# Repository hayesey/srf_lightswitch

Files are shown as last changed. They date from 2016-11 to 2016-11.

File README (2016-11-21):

srf_lightswitch
-----
Originally written sometime in 2015
2016-11-17 put on github
2016-11-21 added filter info
-----

This is my home-made "IoT" light switch.  The idea is that you can retrofit this into a lamp or ceiling light to turn the light on and off remotely.  In addition you can connect up the existing bistable switch (i.e. the light switch) to also operate the light in order to maintain the operation people expect of a light & light switch.

It's based on a Texas Instruments CC1110 System-on-Chip.  The module I use is actually an SRF module from the sadly now defunct Ciseco/Wireless Things company.  This and all other components are mounted to a PCB of my own design.

It uses a PCB mounted mains voltage transformer, this actually powers the microcontroller and other parts of the circuit from the mains voltage going to the light itself.  No batteries are needed or any other means of power.

Files:

'SRF Light Switch' folder contains the design, layout and gerber files for the PCB.  The software I use is Cadsoft Eagle.  I used Seeedstudio Fusion PCB online service for the production of prototype boards.  They are very cheap but since the work is done in China, delivery takes weeks.

'Firmware' folder contains the C code for the CC1110 chip to make the light switch work.  I would definitely call it a prototype, it is probably full of bugs.  It has some basic LLAP commands to control the light switch from other devices such as Ciseco XRF modules.

To use this you'll need the Small Devices C Compiler (sdcc) and some way burning the compiled firmware on to the CC1110 device.  I use a proper TI CC-Debugger, they are under £40.  I believe a Raspberry Pi can also be used to bit-bang it.  See this:

http://paulswasteland.blogspot.co.uk/2015/01/building-your-own-firmware-for-ciseco.html

Use at your own risk anyone who finds this.  I only ever intended this to be for experimentation or fun.

Note - there was an error by me with the PCB layout that didn't come to light until after I had them produced.  This is that I hadn't included the low pass filter on the output of the 3.3v transformer.  Without this the radio performance is very poor.  I made a small veroboard circuit to add the filter, there is an eagle schematic and layout showing this and the parts are included in the BOM.  Values are from the datasheet for the Vigortronix transformer.

Paul Hayes.

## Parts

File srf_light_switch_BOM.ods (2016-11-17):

Part Code | Supplier | Description | Quantity | Price (ea)
2401029 | Farnell | VTX-214-003-103 3W, 3,3v transformer | 1 | £5.64
SRF | Ciseco/Wireless Things | SRF CC1110 surface mount module | 1 | £9.98
1103949 | Farnell | 2.54mm 10way header | 1 | £0.82
2293757 | Farnell | 2.54mm 6way header | 1 | £0.39
1891660 | Farnell | relay, spst-no, 250VAC, 30VDC, 10A | 1 | £0.50
3041440 | Farnell | terminal block, wire to board, 2way | 3 | £0.28
1651089 | Farnell | Diode 1N4001 | 1 | £0.06
1574379 | Farnell | Transistor, NPN, BC337 | 1 | £0.11
9339043 | Farnell | Resistor, 100ohm, +/-5%, 250mW | 1 | £0.04
2328785 | Farnell | 5uH SMD inductor | 1 | £0.41
9696946 | Farnell | 47uF SMD capacitor | 1 | £0.17
645680 | Farnell | enclosure, 25mm/73.5mm/51mm | 1 | £1.33
 |  |  | Total | £19.70

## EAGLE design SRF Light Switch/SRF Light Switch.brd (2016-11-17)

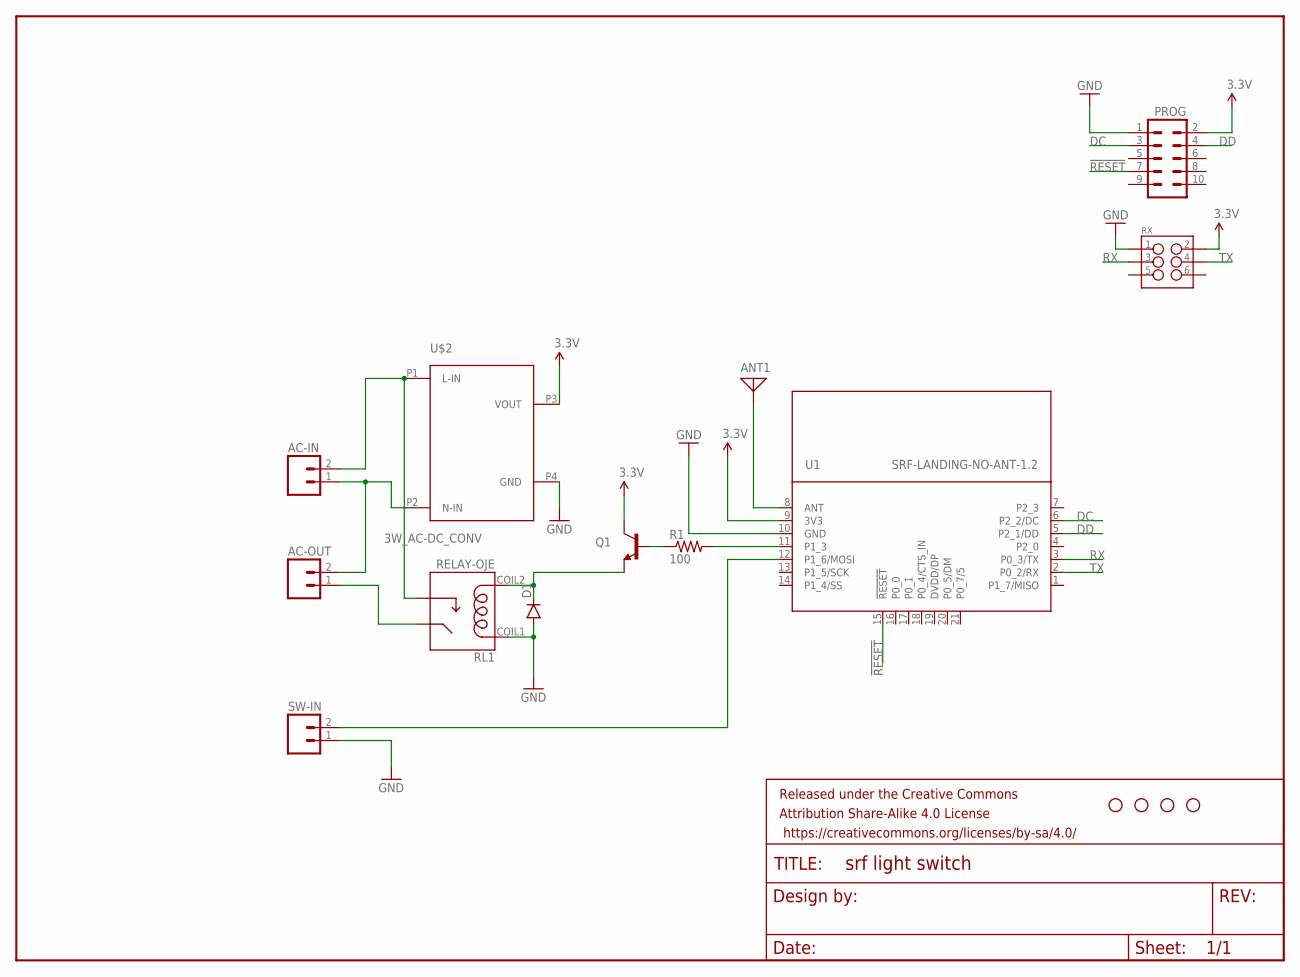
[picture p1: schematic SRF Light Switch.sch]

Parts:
AC-IN: M025MM; SCREWTERMINAL-5MM-2
AC-OUT: M025MM; SCREWTERMINAL-5MM-2
ANT1: ANTENNA; PAD-01
D1: DIODEPTH; DIODE-1N4001
FRAME1: FRAME-LETTER; CREATIVE_COMMONS
PROG: M05X2SHD; 2X5-SHROUDED
Q1: TRANSISTOR_NPNTO92; TO-92
R1: 100; AXIAL-0.4
RL1: RELAY-OJE
RX: M03X2SHROUD; 2X3-SHROUDED
STANDOFF1, STANDOFF2, STANDOFF3, STANDOFF4: STAND-OFF
SW-IN: M025MM; SCREWTERMINAL-5MM-2
U1: SRF-LANDING-NO-ANT-1.2
U$2: 3W_AC-DC_CONV

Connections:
3.3V: PROG.2, Q1.3 (C), RX.2, U1.9 (3V3), U$2.P3 (VOUT)
!RESET: PROG.7, U1.15 (!RESET)
ANT: ANT1.1, U1.8 (ANT)
DC: PROG.3, U1.6 (P2_2/DC)
DD: PROG.4, U1.5 (P2_1/DD)
GND: D1.A, PROG.1, RL1.COIL1, RX.1, SW-IN.1, U1.10 (GND), U$2.P4 (GND)
unnamed: D1.C, Q1.1 (E), RL1.COIL2
unnamed: AC-IN.2, RL1.NO, U$2.P1 (L-IN)
unnamed: SW-IN.2, U1.12 (P1_6/MOSI)
unnamed: Q1.2 (B), R1.P$1 (1)
unnamed: R1.P$2 (2), U1.11 (P1_3)
unnamed: AC-IN.1, AC-OUT.2, U$2.P2 (N-IN)
unnamed: AC-OUT.1, RL1.COM
RX: RX.3, U1.3 (P0_3/TX)
TX: RX.4, U1.2 (P0_2/RX)

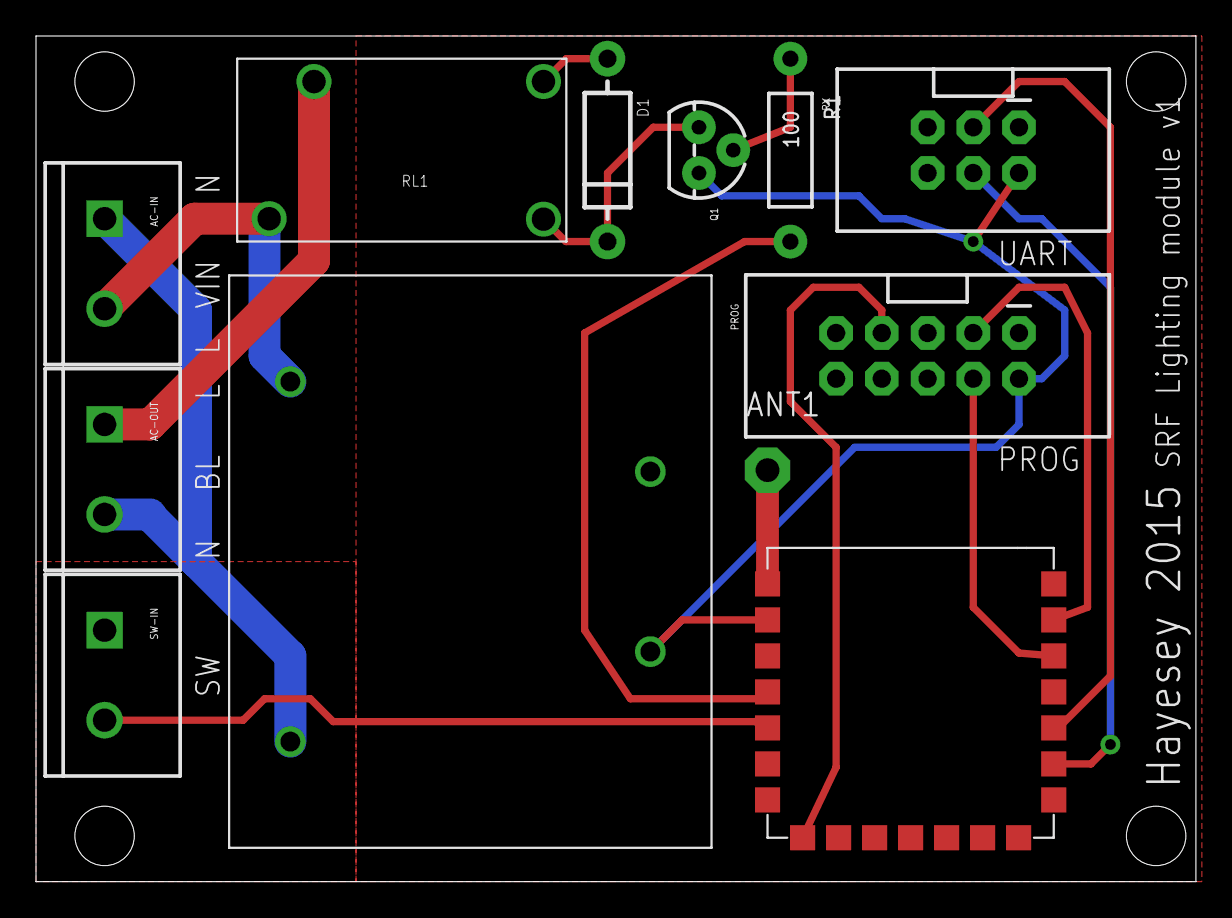
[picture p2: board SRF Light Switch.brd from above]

Board: 2 copper layers, 64.4 x 47.0 mm, 17 parts (0 on the bottom side), 15 nets.

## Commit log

2016-11-17 adding to github
    [SRF Light Switch.brd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]
2016-11-21 added filter veroboard eagle layout
    [srf_filter.brd, srf_filter.sch]
2016-11-21 info about filter add-on board
2017-11-23 added registers spreadsheet
    [radio_registers.ods]

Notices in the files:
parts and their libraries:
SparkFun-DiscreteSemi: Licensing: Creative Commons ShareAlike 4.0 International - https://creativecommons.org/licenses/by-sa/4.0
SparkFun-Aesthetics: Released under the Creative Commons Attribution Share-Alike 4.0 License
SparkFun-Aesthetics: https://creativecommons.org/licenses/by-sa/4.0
